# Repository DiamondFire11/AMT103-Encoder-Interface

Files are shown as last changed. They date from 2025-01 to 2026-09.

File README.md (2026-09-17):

# AMT103 Encoder Interface | SAMD21 CAN-FD Motion Controller








An interrupt-driven hardware interface for Same Sky (formerly CUI Devices) AMT103 quadrature rotary encoders. Designed around an Atmel SAMD21 32-bit ARM Cortex-M0+ MCU and an MCP2518FD CAN-FD controller, this unit processes high-speed incremental feedback and transmits real-time telemetry over an automotive CAN bus.

---

## 📷 PCB CAD Render

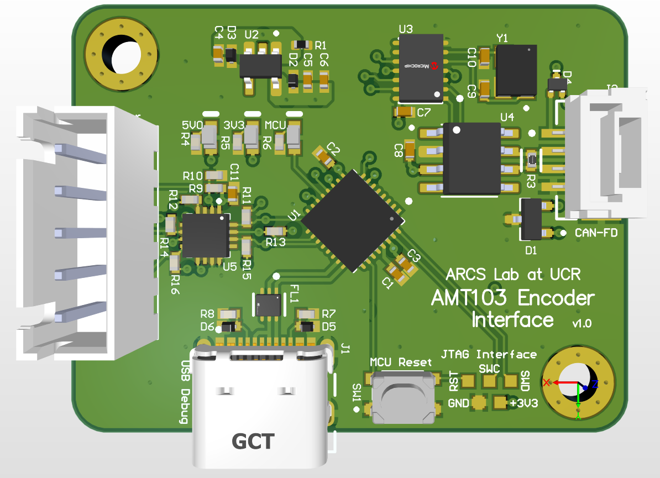
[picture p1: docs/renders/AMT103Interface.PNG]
AMT103 Interface PCB Render


---

## 🛠 Engineering Highlights & System Architecture

* **Automotive-Grade CAN-FD Controller:** Integrates an MCP2518FD controller supporting ISO 11898-1:2015. Features a dedicated 40MHz low-PPM oscillator divided to 20MHz to match microcontroller SPI limits.
* **Interrupt-Driven Quadrature Decoding:** Low-latency C++ firmware captures encoder channels using hardware interrupts, allowing precise high-speed motion tracking without blocking the core execution pipeline.
* **High-Efficiency Power Topology:** Optimized overall board power consumption (~60mW @ 5V), making it suitable for noise-sensitive, battery-powered mobile robotics platforms.
* **Flexible Logic & Power Stage:** Native signal level compatibility across both 3.3V and 5V incremental optical/capacitive quadrature encoders.

---

## 📐 System Technical Specifications

| Parameter | Specification Details |
| :--- | :--- |
| **Microcontroller** | Microchip/Atmel SAMD21E18 (32-bit ARM Cortex-M0+, 48MHz) |
| **CAN Bus Transceiver / Controller** | MCP2518FD (CAN-FD & CAN 2.0B compliant) |
| **System Clocking** | 40MHz Low-PPM Crystal Oscillator (Divided to 20MHz via SPI) |
| **Input Encoder Compatibility** | 3.3V and 5V Incremental Quadrature Encoders (AMT103 Series) |
| **Power Consumption** | ~60mW @ 5V DC |
| **Interfaces & Connectors** | USB 2.0 Type-C, SWD Header, CAN-FD Differential Bus |
| **Manufacturing Deliverables** | Gerber, N.C. Drill, Assembly, Pick-and-Place (PnP), Altium Draftsman |

---

## 🔬 Validation, Testing & Troubleshooting

* **Hardware Bring-Up:** Verified power rails and SPI-to-CAN bridge messaging rates under synthetic bus loads using oscilloscope probing and CAN analyzer tools.
* **SERCOM Arbitration Recovery:** Resolved SAM-BA bootloader execution crashes caused by simultaneous USB and SERCOM bus access during firmware flash operations.
* **Handling Hardware Bootloader:** Force manual bootloader mode prior to binary upload by executing a physical double-tap sequence on the hardware reset pad.

---

## 💻 Firmware Architecture & Flashing

The firmware utilizes a custom PlatformIO board variant forked from the `Adafruit Arduino SAMD Core` to map the custom PCB pin configuration correctly.

```bash
# Clone the repository
git clone https://github.com/DiamondFire11/AMT103-Encoder-Interface.git
cd AMT103-Encoder-Interface

# Build firmware environment with PlatformIO
pio run -e samd21e18_amt103
```

## ⚡ Flashing via SWD & Hardware Debugging
1. Connect an Atmel-ICE or SWD-compatible programmer to the target SWD header pads.
2. Flash the board configuration using PlatformIO or Atmel Studio.
3. **Recovery Mode**: If USB SERCOM arbitration triggers a bus fault during firmware execution, double-tap the physical reset pad to force hardware bootloader mode.
--- 

## 📄 License & Hardware Manufacturing Files
* **Production Files**: Production Gerber (.gbr), N.C. Drill (.drl), Solder Paste Stencils (.gtp/.gbp), and Altium Draftsman assembly drawings are located in the /hardware directory
* **License**: Distributed under [GPLv3 License](https://github.com/DiamondFire11/Tartarus-Joystick-Mod/blob/main/LICENSE).

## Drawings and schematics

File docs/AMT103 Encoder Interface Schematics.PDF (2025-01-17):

## CAN-FD

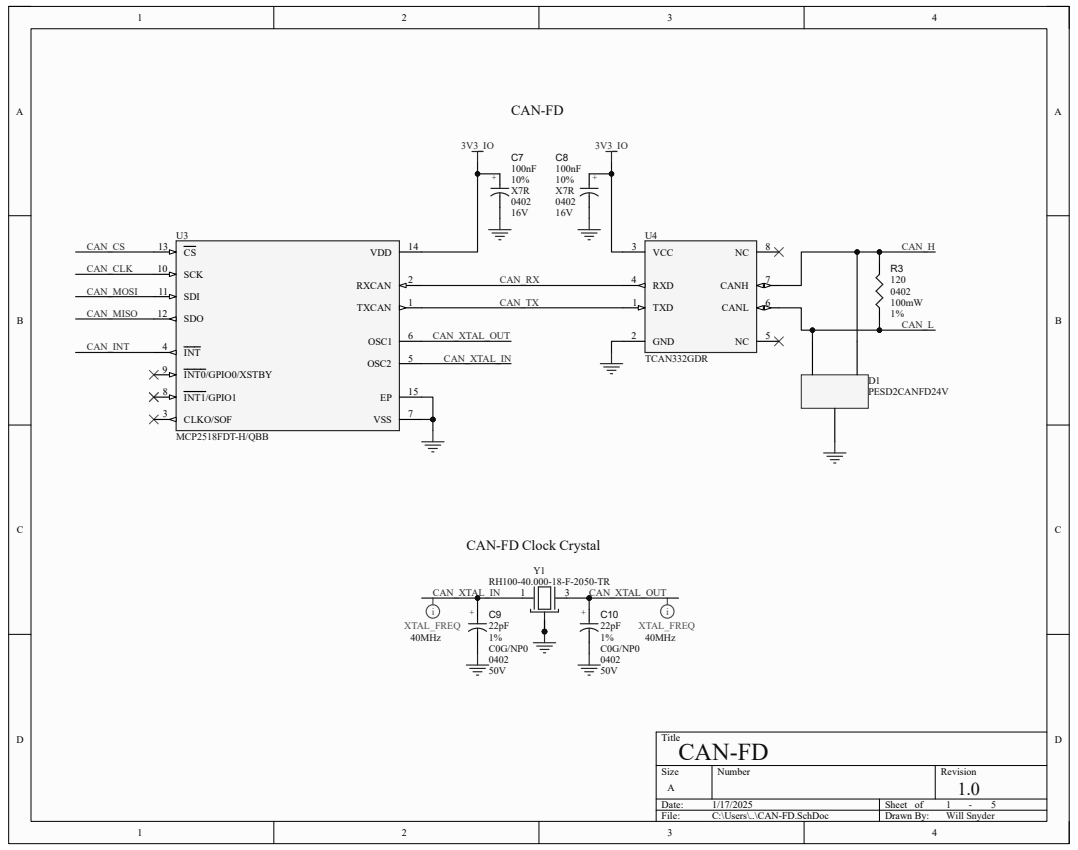
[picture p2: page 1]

CAN-FD Clock Crystal

## Status LEDs

## USB Type C Port

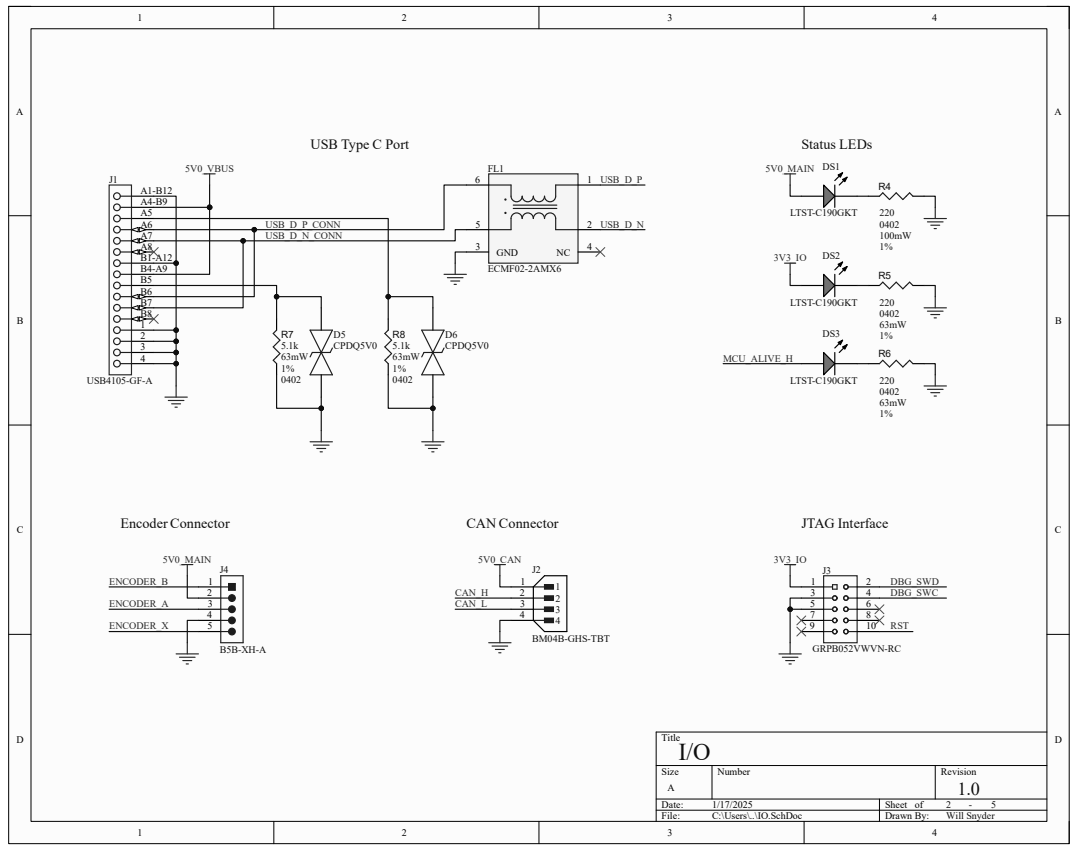
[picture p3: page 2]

## Atmel SAM D21

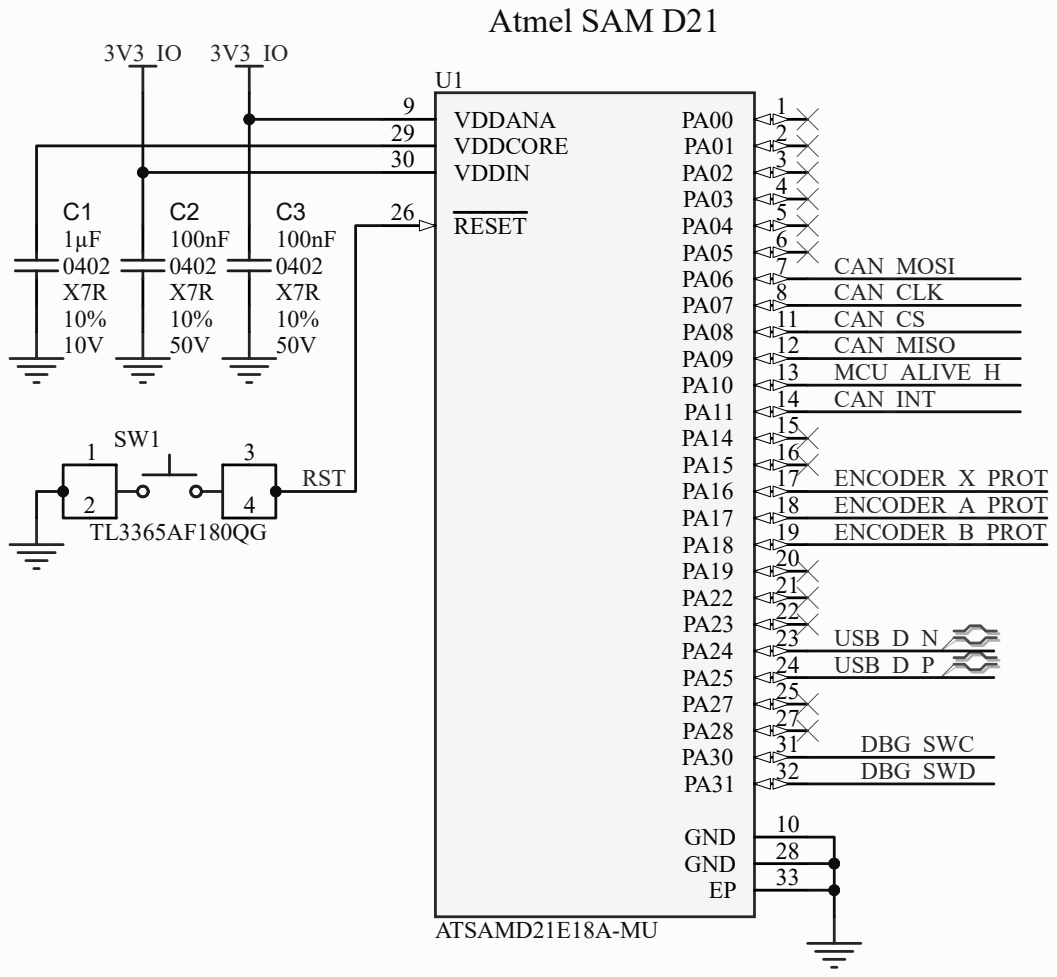
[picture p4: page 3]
Title; Size; Number; Revision; File:; C:\Users\..\MCU.SchDoc; Drawn By:; VDDANA 9 VDDCORE 29 VDDIN 30; RESET 26; GND; ATSAMD21E18A-MU; DBG_SWC DBG_SWD; MCU_ALIVE_H; USB_D_N USB_D_P; RST; ENCODER_B_PROT; ENCODER_A_PROT; ENCODER_X_PROT; CAN_MOSI CAN_CLK; CAN_MISO; CAN_CS; CAN_INT; MCU

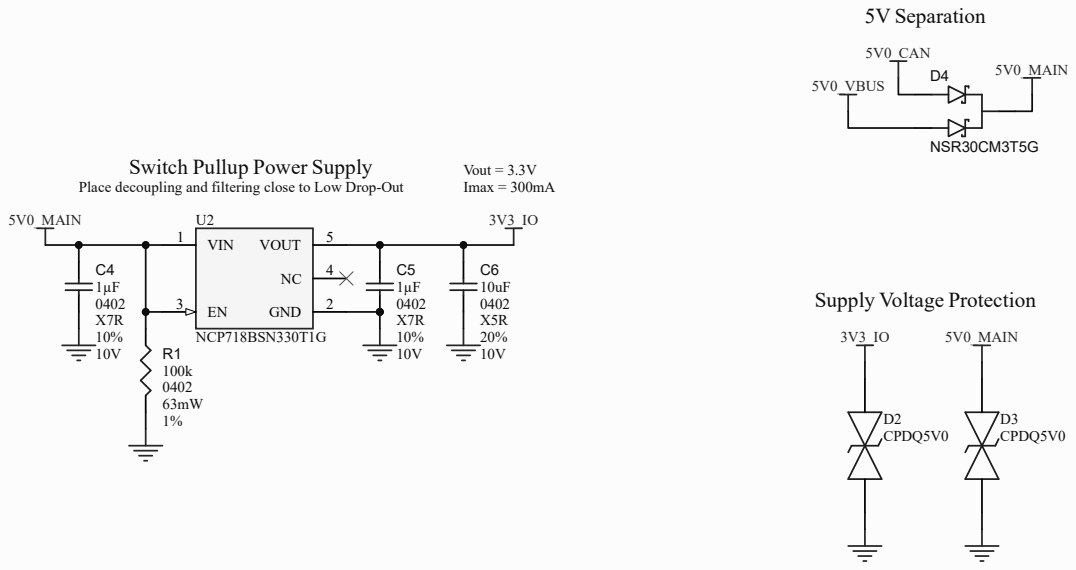
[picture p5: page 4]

Place decoupling and filtering close to Low Drop-Out

## 5V0 to 3V3 Logic Level Shift

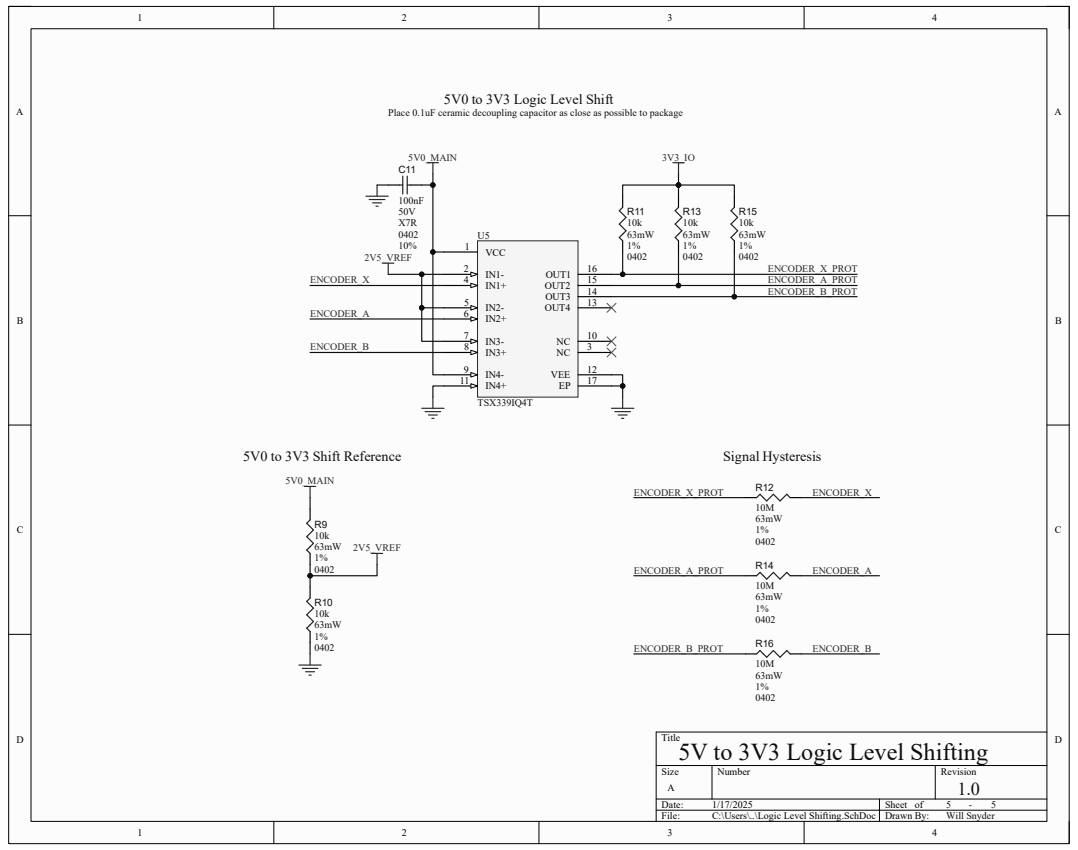
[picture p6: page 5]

Place 0.1uF ceramic decoupling capacitor as close as possible to package

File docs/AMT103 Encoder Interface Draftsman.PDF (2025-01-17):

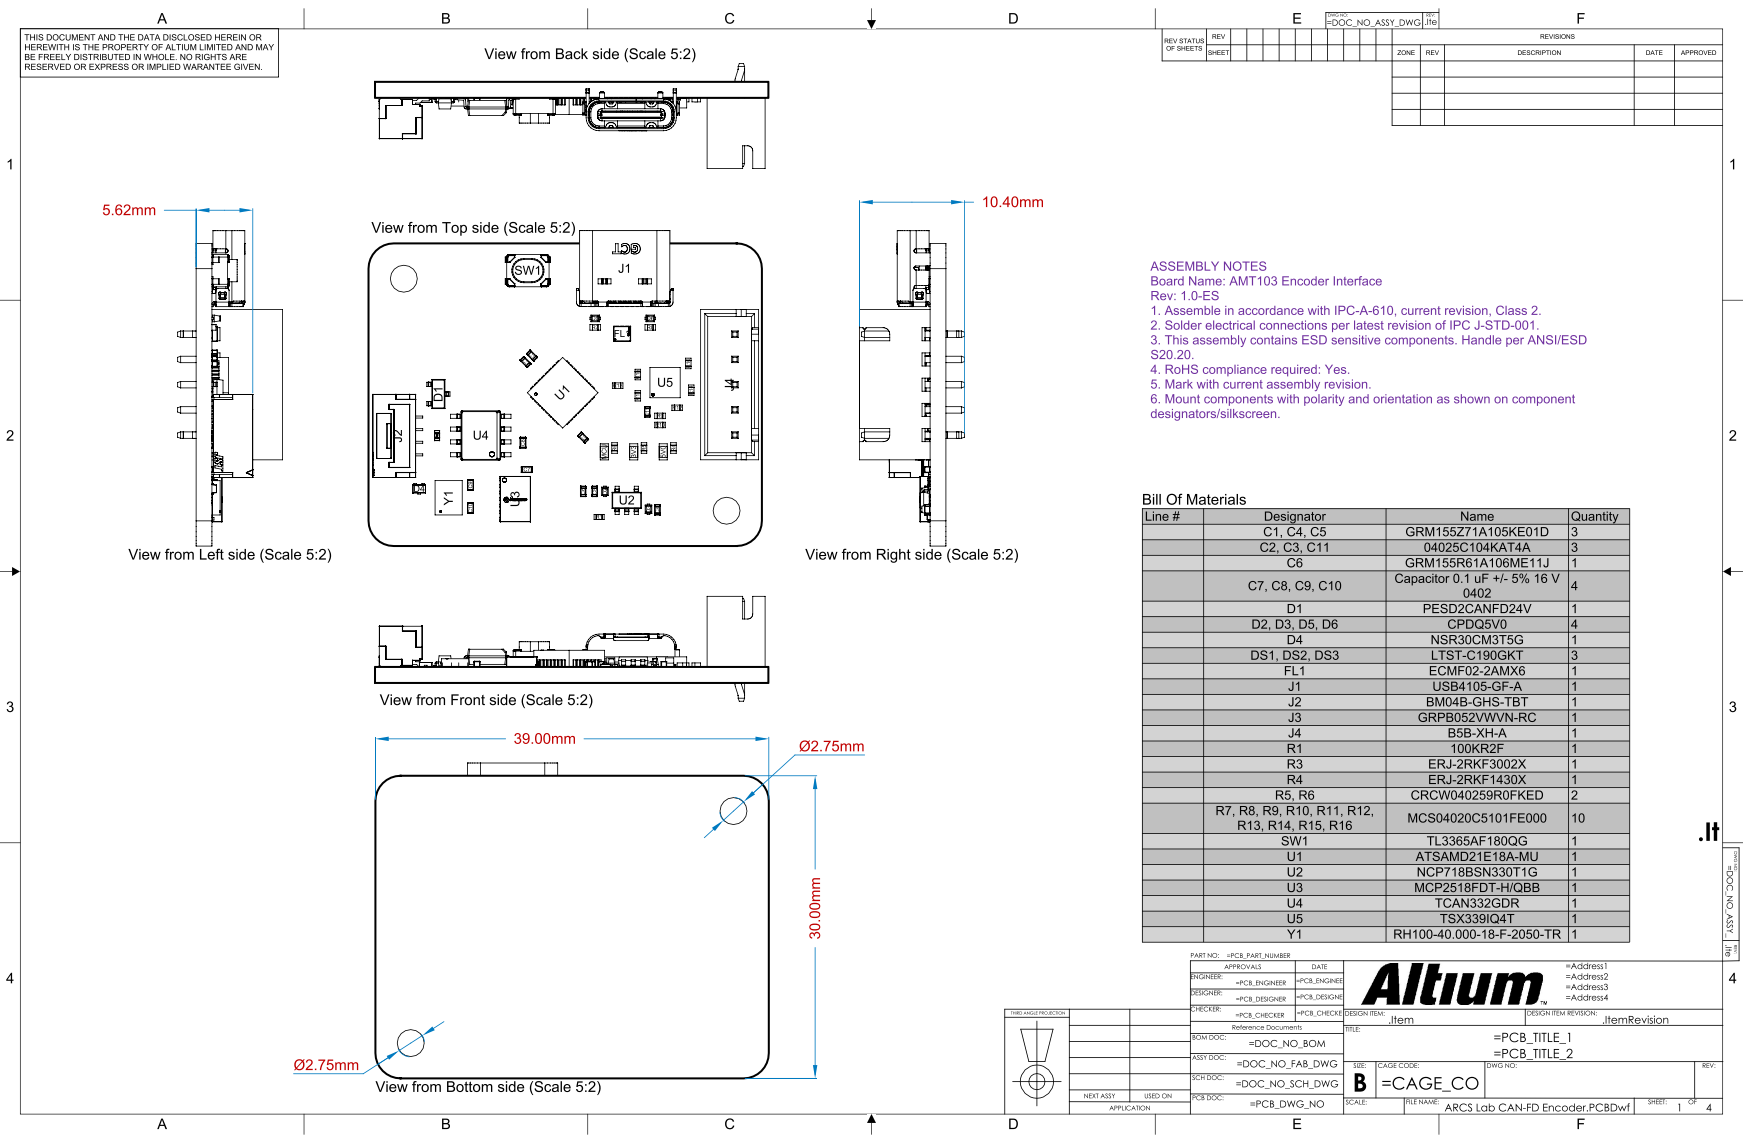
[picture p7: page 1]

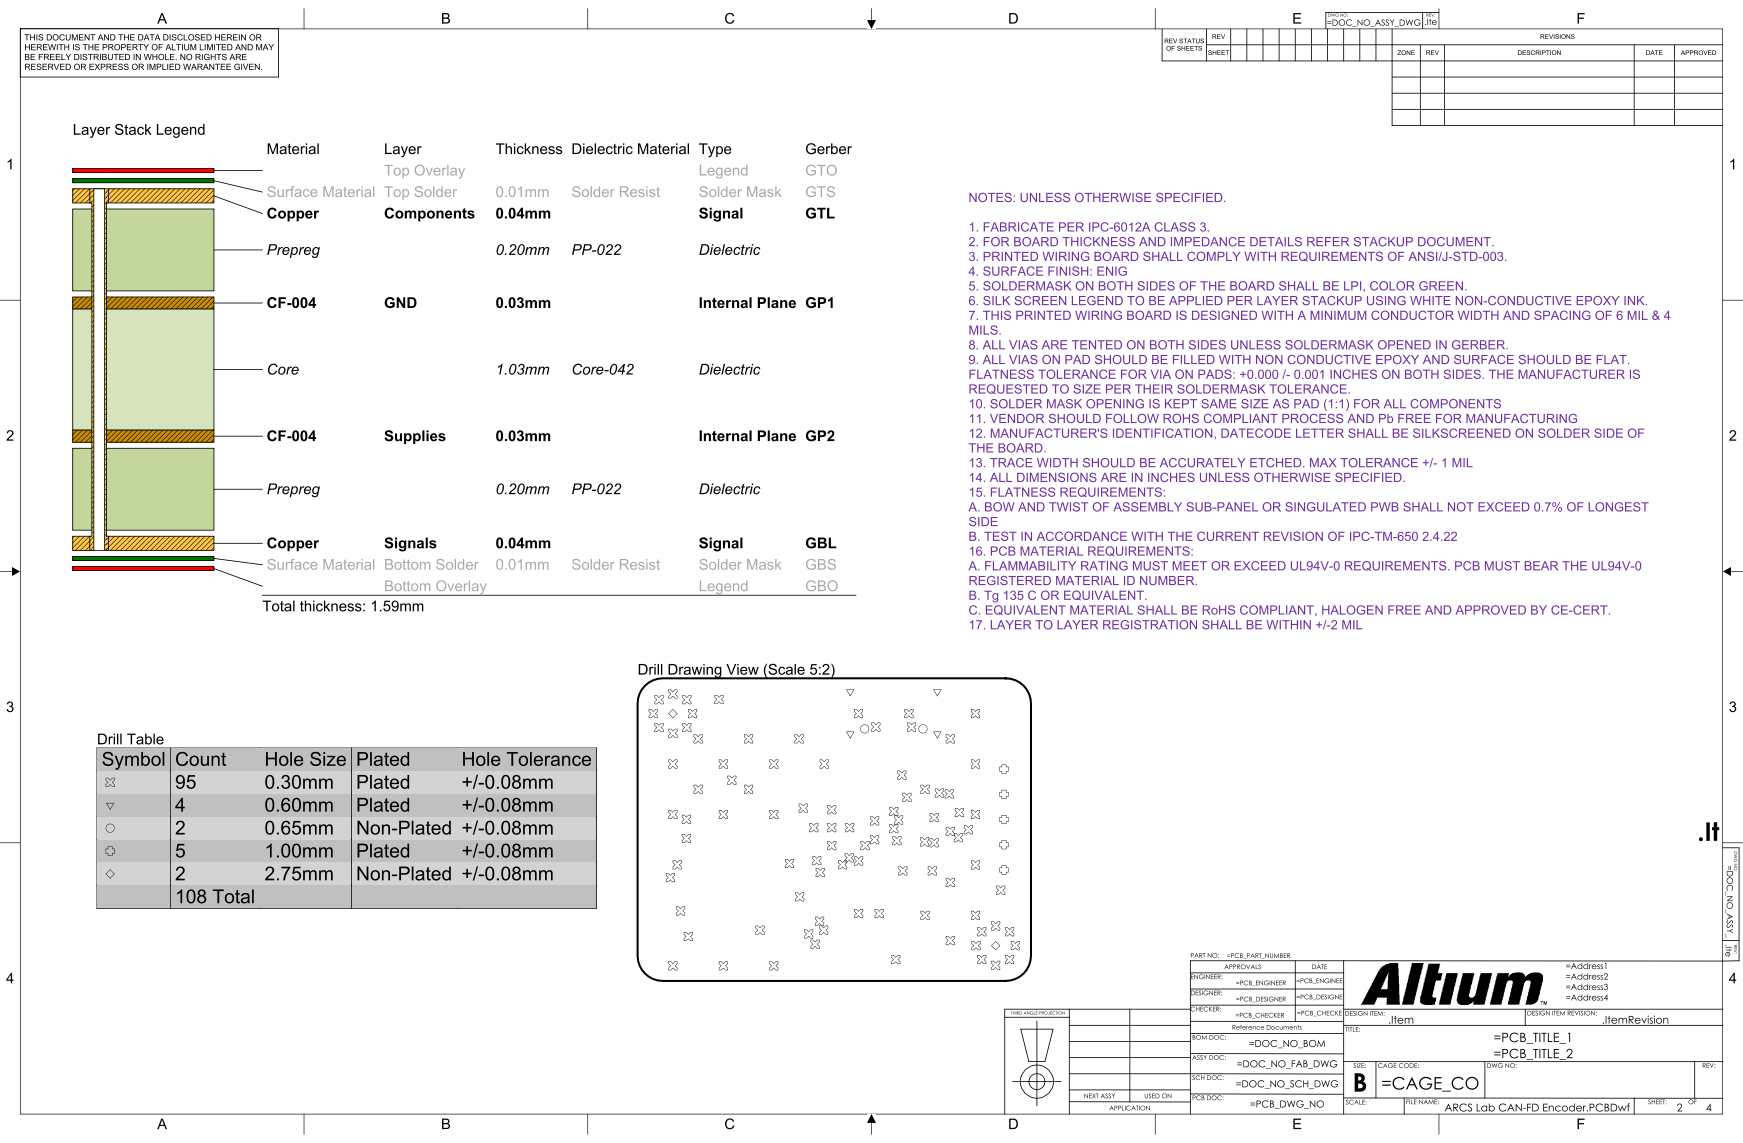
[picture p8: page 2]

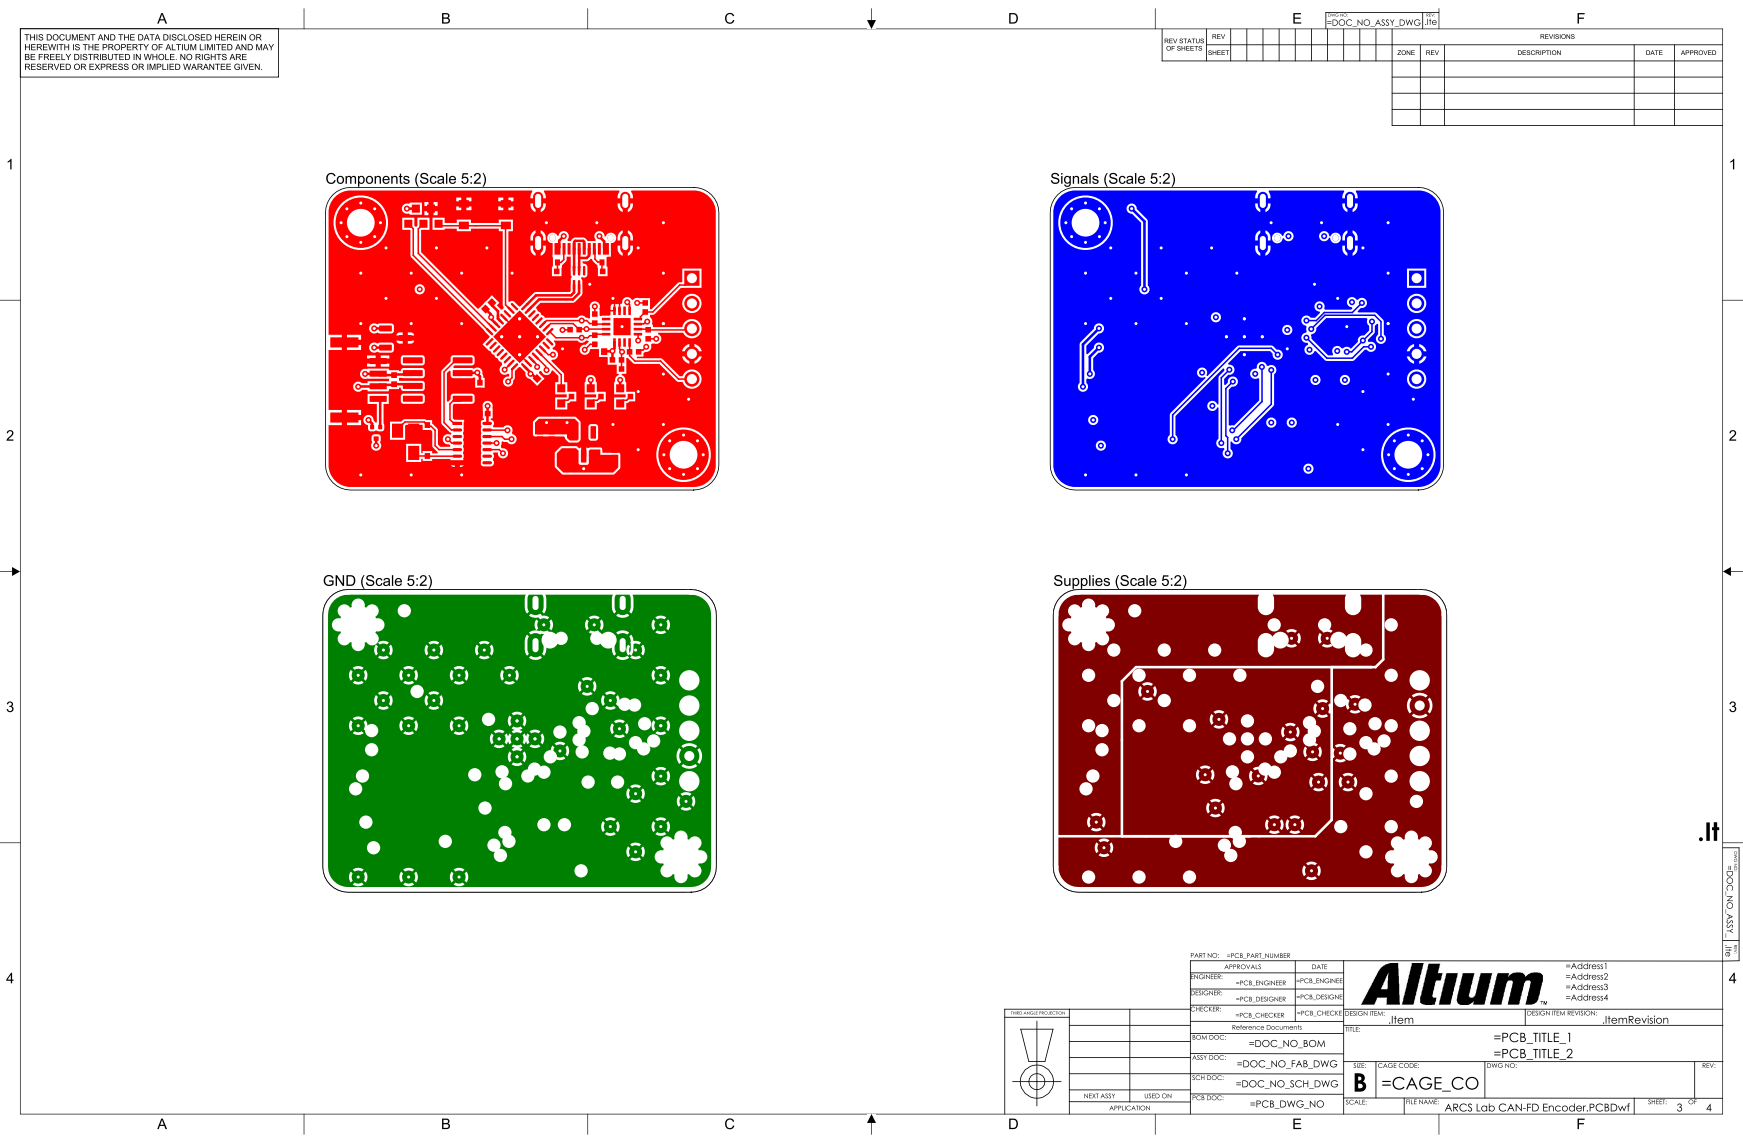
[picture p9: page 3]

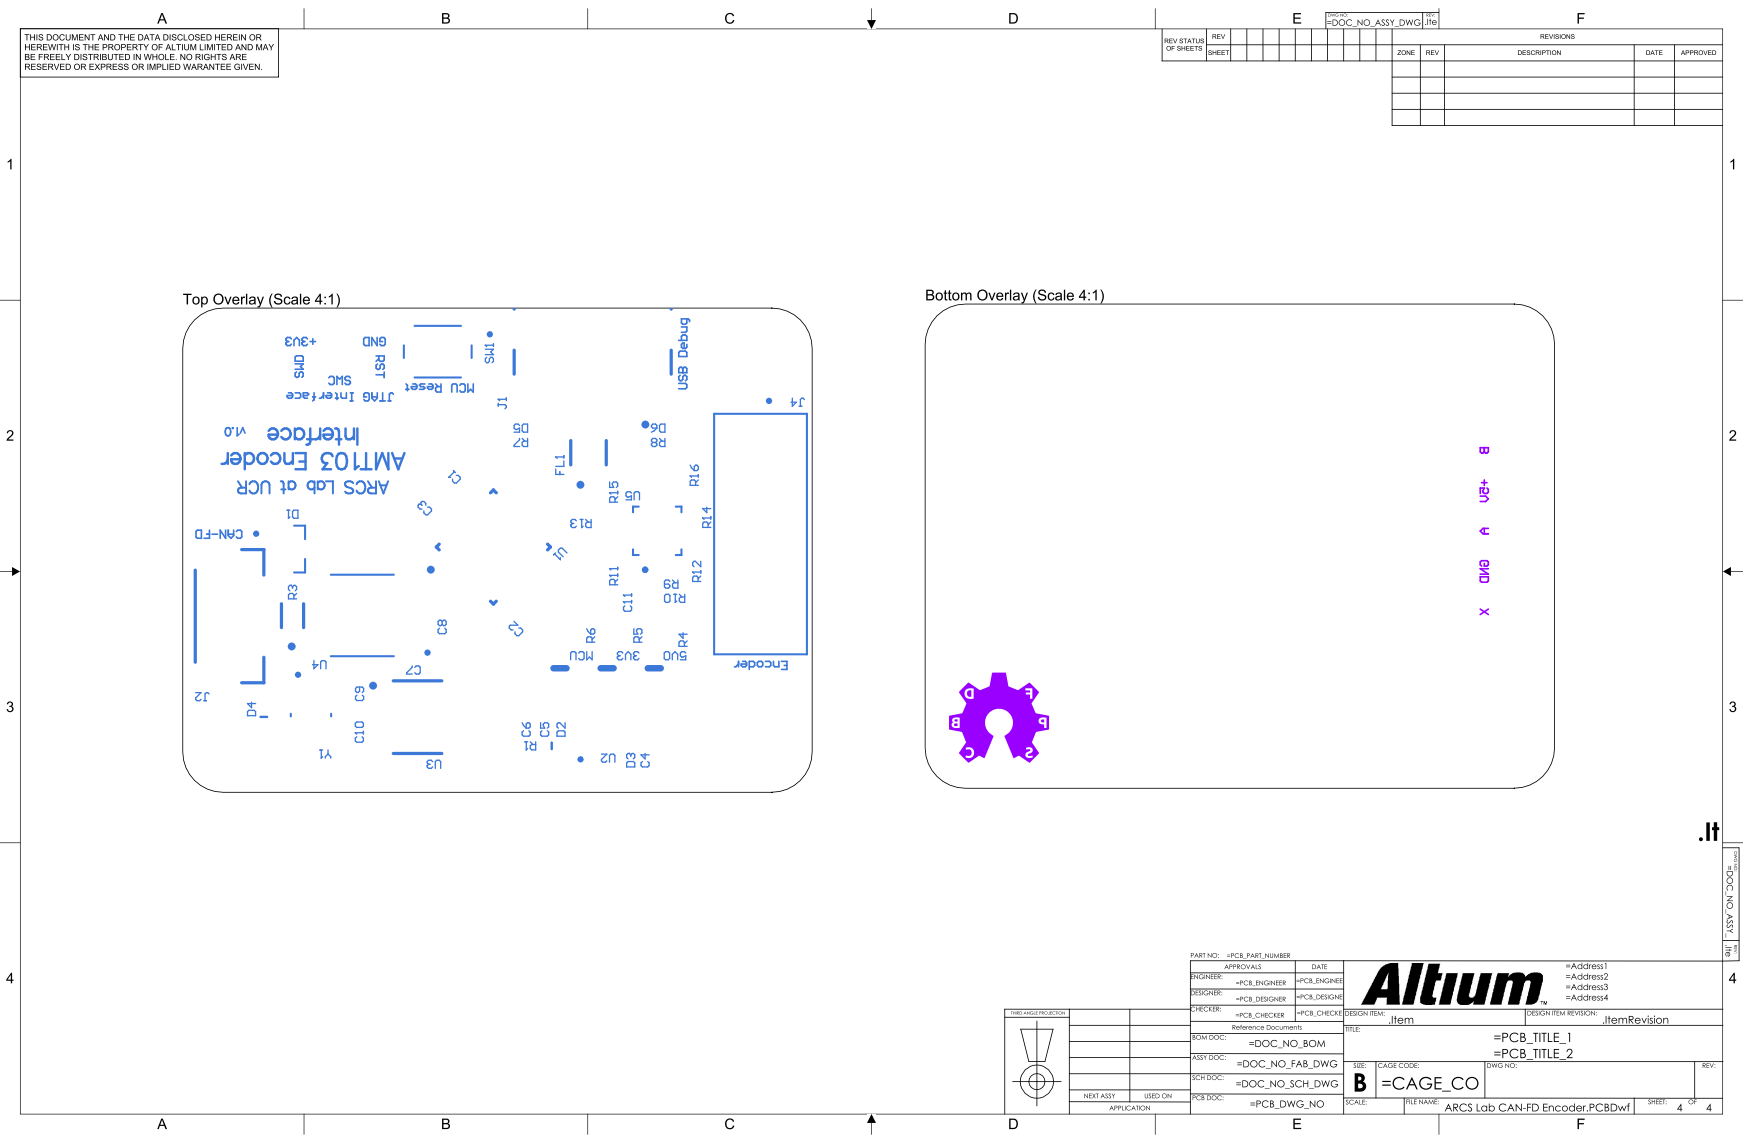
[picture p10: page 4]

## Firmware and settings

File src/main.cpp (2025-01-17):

#include <Arduino.h>
#include <cmath>

#define ENCODER_USE_INTERRUPTS
#define ENCODER_ID 0x01

// Include Paul Stoffregen's Encoder library and MCP2517FD library
#include "Encoder.h"
#include "ACAN2517FD.h"
#include <SPI.h>

#include "../include/encoderFSM.h"
#include "../include/ledFSM.h"

ACAN2517FD CAN(CAN_CS, SPI, CAN_INT);
CANFDMessage canFrame;
uint8_t frameID = ENCODER_ID;
bool isCANGood = false;

Encoder encoder(ENCODER_A, ENCODER_B);
int32_t encoderPos; // Encoder position

struct Tasks {
    uint8_t state;
    uint32_t period;
    uint32_t elapsedTime;
    uint8_t (*tickFcn) (uint8_t);
} typedef Tasks;

Tasks tasks[2]; // Array storing FSMs

void setup() {
    // Initialize MCU Alive LED
    pinMode(LED_BUILTIN, OUTPUT);
    digitalWrite(LED_BUILTIN, LOW);

    // Wait for Serial to connect - Break and continue boot after 5s
    Serial.begin(115200);
    while (!Serial && millis() < 5000) {
        delay (50);
        digitalWrite (LED_BUILTIN , !digitalRead (LED_BUILTIN));
    }

    SPI.begin();    // Start SPI bus
    initCAN();      // Initialize CAN-FD controller

    tasks[0].state = LEDStates::LED_INIT;
    tasks[0].period = 500;
    tasks[0].elapsedTime = 0;
    tasks[0].tickFcn = &ledTick;

    tasks[1].state = EncoderStates::ENCODER_INIT;
    tasks[1].period = 5;
    tasks[1].elapsedTime = 0;
    tasks[1].tickFcn = &encoderTick;
}

void loop() {
    for (auto & task : tasks) {
        if ((millis() - task.elapsedTime) >= task.period) {
            task.state = task.tickFcn(task.state);
            task.elapsedTime = millis(); // Last time this task was ran
        }
    }
}

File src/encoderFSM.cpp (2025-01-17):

#include "../include/encoderFSM.h"

uint8_t encoderTick(uint8_t state) {
    state = encoderTransition(state);
    encoderAction(state);
    return state;
}

uint8_t encoderTransition(uint8_t state) {
    switch(state){
        case EncoderStates::ENCODER_INIT:
        case EncoderStates::TRANSMIT:
            state = EncoderStates::READ;
            break;

        case EncoderStates::READ:
            state = EncoderStates::TRANSMIT;
            break;

        default:
            state = EncoderStates::ENCODER_INIT;
    }

    return state;
}

void encoderAction(uint8_t state) {
    switch(state){
        case EncoderStates::ENCODER_INIT:
            Serial.println("AMT103 encoder initialized");
            break;

        case EncoderStates::READ:
            readEncoder();
            break;

        case EncoderStates::TRANSMIT:
            if(isCANGood){
                transmitToCAN();
            }
            break;

        default:
            Serial.println("Error: Encountered unknown state, resetting SM.");
    }
}

void initCAN() {
    /* MCP2518FD Settings -
     * Oscillator: 40MHz
     * Arbitration Rate: 500 kbit/s
     * Data Rate: 2 Mbit/s (500kbit/s * 4)
     */
    ACAN2517FDSettings settings(ACAN2517FDSettings::OSC_40MHz_DIVIDED_BY_2,
                                500UL * 1000UL,
                                DataBitRateFactor::x4);

    settings.mRequestedMode = ACAN2517FDSettings::NormalFD; // Request start in NORMAL FD mode

    const uint32_t canInitErrCode = CAN.begin(settings, [] {CAN.isr(); });
    if (canInitErrCode != 0) {
        Serial.print ("CAN Configuration Error: 0x");
        Serial.println (canInitErrCode , HEX);
    } else {
        isCANGood = true; // CAN is good, print CAN Tx/Rx settings
        outputCANSettings(settings);

        // Setup CAN Frame obj
        canFrame.id = frameID;
        canFrame.len = 4;
    }
}

void readEncoder() {
    encoderPos = encoder.read();
}

bool transmitToCAN() {
    canFrame.data_s32[0] = encoderPos;
    return CAN.tryToSend(canFrame);
}

void outputCANSettings(ACAN2517FDSettings & settings) {
    Serial.println("<--- MCP2518FD Settings --->");

    Serial.print("Operating Mode: ");
    switch(settings.mRequestedMode){
        case ACAN2517FDSettings::NormalFD:
            Serial.println("NormalFD");
            break;
        case ACAN2517FDSettings::Sleep:
            Serial.println("Sleep");
            break;
        case ACAN2517FDSettings::InternalLoopBack:
            Serial.println("InternalLoopBack");
            break;
        case ACAN2517FDSettings::ListenOnly:
            Serial.println("ListenOnly");
            break;
        case ACAN2517FDSettings::Configuration:
            Serial.println("Configuration");
            break;
        case ACAN2517FDSettings::ExternalLoopBack:
            Serial.println("ExternalLoopBack");
            break;
        case ACAN2517FDSettings::Normal20B:
            Serial.println("Normal20B");
            break;
        case ACAN2517FDSettings::RestrictedOperation:
            Serial.println("RestrictedOperation");
            break;
        default:
            Serial.println("Operation mode unknown");
    }

    Serial.print("Oscillator (MHz): ");
    switch(settings.oscillator()) {
        case ACAN2517FDSettings::OSC_4MHz:
            Serial.println("4");
            break;
        case ACAN2517FDSettings::OSC_4MHz_DIVIDED_BY_2:
            Serial.println("2");
            break;
        case ACAN2517FDSettings::OSC_4MHz10xPLL:
            Serial.println("4 * 10");
            break;
        case ACAN2517FDSettings::OSC_4MHz10xPLL_DIVIDED_BY_2:
            Serial.println("2 * 10");
            break;
        case ACAN2517FDSettings::OSC_20MHz:
            Serial.println("20");
            break;
        case ACAN2517FDSettings::OSC_20MHz_DIVIDED_BY_2:
            Serial.println("10");
            break;
        case ACAN2517FDSettings::OSC_40MHz:
            Serial.println("40");
            break;
        case ACAN2517FDSettings::OSC_40MHz_DIVIDED_BY_2:
            Serial.println("20");
            break;
    }

    Serial.print("SYSCLK Frequency (MHz): ");
    Serial.println(settings.sysClock()/1000000.0);

    Serial.print("Bitrate Prescaler: ");
    Serial.println(settings.mBitRatePrescaler);

    Serial.print("Arbitration Rate Is Closed To Desired Rate: ");
    Serial.println(settings.mArbitrationBitRateClosedToDesiredRate ? "Yes" : "No!");

    Serial.print("Distance (PPM): ");
    Serial.println(settings.ppmFromDesiredArbitrationBitRate());

    Serial.print("Consistency: ") ;
    Serial.println(settings.CANBitSettingConsistency() ? "FAIL" : "Ok");

    Serial.println("\n<--  Arbitration Settings  -->");

    Serial.print("Actual Arbitration Rate (kbit/s): ");
    Serial.println(settings.actualArbitrationBitRate()/1000.0);

    Serial.print("Arbitration Phase Segment 1 (Tq): ");
    Serial.println(settings.mArbitrationPhaseSegment1);

    Serial.print("Arbitration Phase Segment 2 (Tq): ");
    Serial.println(settings.mArbitrationPhaseSegment2);

    Serial.print("Arbitration Resynchronization Jump Width: ");
    Serial.println(settings.mArbitrationSJW);

    Serial.print("Arbitration Sample Point: ");
    Serial.print(settings.arbitrationSamplePointFromBitStart()) ; // 81, meaning 81%") ;
    Serial.println("%");

    Serial.println("\n<--  Frame Data Settings  -->");

    Serial.print("Actual Data Bitrate (kbit/s): ");
    Serial.println(settings.actualDataBitRate ()/1000.0);

    Serial.print("Data Phase Segment 1 (Tq): ");
    Serial.println(settings.mDataPhaseSegment1);

    Serial.print("Data Phase Segment 2 (Tq): ");
    Serial.println(settings.mDataPhaseSegment2);

    Serial.print ("Data Resynchronization Jump Width: ");
    Serial.println(settings.mDataSJW);

    Serial.print("Data Sample Point: ");
    Serial.print(settings.dataSamplePointFromBitStart());
    Serial.println("%");

    Serial.println("<--- MCP2518FD Settings --->");
}

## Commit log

2025-01-17 Update and rename hardware/GERBER/AMT103 Encoder Interface-RoundHoles.TXT to hardware/GERBER/NC Drill/AMT103 Encoder Interface-RoundHoles.TXT
2025-01-17 Update and rename hardware/GERBER/AMT103 Encoder Interface-SlotHoles.TXT to hardware/GERBER/NC Drill/AMT103 Encoder Interface-SlotHoles.TXT
2025-01-17 Update and rename hardware/GERBER/ARCS Lab CAN-FD Encoder.GBP to hardware/GERBER/Stencils/ARCS Lab CAN-FD Encoder.GBP
    [ARCS Lab CAN-FD Encoder.GBP]
2025-01-17 Rename hardware/GERBER/ARCS Lab CAN-FD Encoder.GTP to hardware/GERBER/Stencils/ARCS Lab CAN-FD Encoder.GTP
    [ARCS Lab CAN-FD Encoder.GTP]
2025-01-17 Update and rename hardware/GERBER/Stencils/ARCS Lab CAN-FD Encoder.GBL to hardware/GERBER/ARCS Lab CAN-FD Encoder.GBL
    [ARCS Lab CAN-FD Encoder.GBL]
2025-01-17 Update and rename hardware/GERBER/Stencils/ARCS Lab CAN-FD Encoder.GBO to hardware/GERBER/ARCS Lab CAN-FD Encoder.GBO
    [ARCS Lab CAN-FD Encoder.GBO]
2025-01-17 Update and rename hardware/GERBER/Stencils/ARCS Lab CAN-FD Encoder.GBS to hardware/GERBER/ARCS Lab CAN-FD Encoder.GBS
    [ARCS Lab CAN-FD Encoder.GBS]
2025-01-17 Update and rename hardware/GERBER/Stencils/ARCS Lab CAN-FD Encoder.GM to hardware/GERBER/ARCS Lab CAN-FD Encoder.GM
2025-01-17 Update and rename hardware/GERBER/Stencils/ARCS Lab CAN-FD Encoder.GM6 to hardware/GERBER/ARCS Lab CAN-FD Encoder.GM6
2025-01-17 Update and rename hardware/GERBER/Stencils/ARCS Lab CAN-FD Encoder.GM7 to hardware/GERBER/AMT103 Encoder Interface.GM7
2025-01-17 Update and rename ARCS Lab CAN-FD Encoder.GBP to AMT103 Encoder Interface.GBP
    [AMT103 Encoder Interface.GBP]
2025-01-17 Update and rename hardware/GERBER/Stencils/ARCS Lab CAN-FD Encoder.GP1 to hardware/GERBER/AMT103 Encoder Interface.GP1
2025-01-17 Update and rename ARCS Lab CAN-FD Encoder.GBL to AMT103 Encoder Interface.GBL
    [AMT103 Encoder Interface.GBL]
2025-01-17 Update and rename ARCS Lab CAN-FD Encoder.GBO to AMT103 Encoder Interface.GBO
    [AMT103 Encoder Interface.GBO]
2025-01-17 Update and rename ARCS Lab CAN-FD Encoder.GBS to AMT103 Encoder Interface.GBS
    [AMT103 Encoder Interface.GBS]
2025-01-17 Update and rename ARCS Lab CAN-FD Encoder.GM to AMT103 Encoder Interface.GM
2025-01-17 Update and rename ARCS Lab CAN-FD Encoder.GM6 to AMT103 Encoder Interface.GM6
2025-01-17 Update and rename hardware/GERBER/Stencils/ARCS Lab CAN-FD Encoder.GP2 to hardware/GERBER/AMT103 Encoder Interface.GP2
2025-01-17 Update and rename hardware/GERBER/Stencils/ARCS Lab CAN-FD Encoder.GPB to hardware/GERBER/AMT103 Encoder Interface.GPB
2025-01-17 Update and rename hardware/GERBER/Stencils/ARCS Lab CAN-FD Encoder.GPT to hardware/GERBER/AMT103 Encoder Interface.GPT
2025-01-17 Update and rename hardware/GERBER/Stencils/ARCS Lab CAN-FD Encoder.GTL to hardware/GERBER/AMT103 Encoder Interface.GTL
    [AMT103 Encoder Interface.GTL]
2025-01-17 Update and rename hardware/GERBER/Stencils/ARCS Lab CAN-FD Encoder.GTO to hardware/GERBER/AMT103 Encoder Interface.GTO
    [AMT103 Encoder Interface.GTO]
2025-01-17 Update and rename hardware/GERBER/Stencils/ARCS Lab CAN-FD Encoder.GTS to hardware/GERBER/AMT103 Encoder Interface.GTS
    [AMT103 Encoder Interface.GTS]
2025-01-17 Rename ARCS Lab CAN-FD Encoder.GTP to AMT103 Encoder Interface.GTP
    [AMT103 Encoder Interface.GTP]
2025-01-17 Update and rename ARCS Lab CAN-FD Encoder.BomDoc to AMT103 Encoder Interface.BomDoc
2025-01-17 Rename ARCS Lab CAN-FD Encoder.PCBDwf to AMT103 Encoder Interface.PCBDwf
2025-01-17 Rename ARCS Lab CAN-FD Encoder.PcbDoc to AMT103 Encoder Interface.PcbDoc
    [AMT103 Encoder Interface.PcbDoc, ARCS Lab CAN-FD Encoder.PcbDoc]
2025-01-17 Update and rename ARCS Lab CAN-FD Encoder.PrjPcb to AMT103 Encoder Interface.PrjPcb
    [AMT103 Encoder Interface.PrjPcb]
2025-01-17 Update AMT103 Encoder Interface.PrjPcb
    [AMT103 Encoder Interface.PrjPcb]
2025-01-17 Update and rename ARCS Lab CAN-FD Encoder.PrjPcbStructure to AMT103 Encoder Interface.PrjPcbStructure
2025-01-17 Update README.md
    Changed board and code upload sections
2026-09-17 Revise README for AMT103 Encoder Interface
    Updated the README to enhance clarity and added visual elements.
2026-09-17 Refine README description and highlights
    Updated description to clarify telemetry transmission over an automotive CAN bus. Removed redundant mention of functional safety compliance.

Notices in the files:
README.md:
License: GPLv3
